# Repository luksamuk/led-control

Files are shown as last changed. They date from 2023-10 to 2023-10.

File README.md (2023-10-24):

# LED Control

Iluminação IoT usando LEDs NeoPixel, controle remoto e mudança automática de iluminação.

A intenção original era criar um sistema simples de iluminação dinâmica para o meu quarto, usando IoT, e também permitir controlar isso remotamente (já que não tenho interruptor próximo à minha cama...), além de mudar automaticamente a iluminação em certos momentos do dia.

## Servidor no Raspberry Pi Pico W

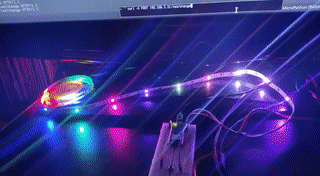
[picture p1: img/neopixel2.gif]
Exemplo do circuito de LEDs em execução


Vamos usar o Raspberry Pi Pico W como um servidor HTTP 1.1 e também como um controlador para os LEDs NeoPixel. Esse dispositivo possui uma antena Wi-Fi, por isso ele é ideal para um servidor HTTP IoT.

### Circuito

Os requisitos mínimos para montar o projeto são:

- Uma protoboard ([uma de 400 pontos](https://www.makerhero.com/produto/protoboard-400-pontos/) é o suficiente);
- Um [Raspberry Pi Pico W](https://www.makerhero.com/produto/raspberry-pi-pico-w/) (deve ser este modelo, para que conectemos ao Wi-Fi -- lembre-se de soldar [pinos](https://www.makerhero.com/produto/barra-de-pinos-1x40-torneada-180-graus/) em ambas as extremidades para conectar à protoboard!);
- 7 [jumpers](https://www.makerhero.com/produto/kit-jumpers-10cm-x120-unidades/) macho-macho (para montar o circuito. Três desses jumpers são saídas para os LEDs, e podem ser substituídos por jumpers macho-fêmea a depender da extremidade usada);
- Uma [Fita de LED RGB WS2812 5050 de 1 metro](https://www.makerhero.com/produto/fita-de-led-rgb-ws2812-5050-1m/);
- Uma [chave táctil push-button](https://www.makerhero.com/produto/chave-tactil-push-button/).

A montagem pode ser feita de acordo com essa [esquemática](./img/breadboard.png).

### Instalação

O projeto encontra-se na pasta `rpi-pico-w`.

1. [Baixe a IDE Thonny](https://thonny.org/).
2. [Conecte seu Raspberry Pi Pico W e instale o MicroPython](https://projects.raspberrypi.org/en/projects/get-started-pico-w/1).
2. Vá ao menu `Ferramentas` > `Gerenciar pacotes`. Instale os pacotes `picozero` e `neopixel`.
3. Abra o arquivo `main.py`. Altere as variáveis `SSID` e `PASSWD` para as suas credenciais do seu Wi-Fi.
4. Você poderá executar a aplicação para testar nesse momento. Para fazer com que o MicroPython fique responsivo novamente, basta parar a aplicação.
5. Após testar, selecione a opção para salvar o script, e salve-o no seu Raspberry Pi Pico W, *exatamente com o nome `main.py`*.

Caso você tenha acesso à sua configuração do roteador, recomendo definir um IP estático para o Raspberry Pi Pico W.

### Comportamento e Rotas

Abaixo temos uma breve descrição dos comportamentos do servidor e das rotas que podem ser usadas.

**Todas as rotas retornam um documento JSON** com o seguinte formato:

```json
{
    "blinking": true,
    "program": 2,
    "dim": 0.1474,
    "color": "ffa648"
}
```

- `blinking`: Se os LEDs estão ligados ou não.
- `program`: Programa sendo executado. Os programas são sempre um dos números `0` (modo Natal), `1` (modo Rastro) e `2` (modo Lâmpada -- padrão).
- `dim`: Nível de intensidade da luz. Deve ser um número entre `0.02` e `1.0`.
- `color`: Cor atual dos LEDs (apenas para o modo Lâmpada). Trata-se de uma string com valores hexadecimais no formato `ffffff`.

Os valores de `program`, `dim` e `color` podem ser alterados e retornados normalmente, mesmo que o LED esteja desativado. Igualmente, o valor de `color` também pode ser alterado e retornado, mesmo que o equipamento não esteja no modo Lâmpada.

Caso você realize uma requisição em uma rota desconhecida, o servidor retornará um erro `404`.

#### Status do servidor

- `GET /led`

Retorna o status da aplicação, sem realizar nenhuma modificação.

#### Ligar/Desligar

- `POST /led/on`
- `POST /led/off`
- `POST /led/toggle`

Liga ou desliga os LEDs. Desligar os LEDs não desligará o servidor. A terceira rota inverte o estado atual de ligado/desligado.

#### Mudar programação

- `POST /led/program/{id}`
- `POST /led/change`

Muda a atual programação dos LEDs. A primeira rota coloca uma programação em específico, e a segunda muda para a próxima programação na ordem. O `id` dever corresponder ao número do programa, como descrito mais acima.

#### Mudar intensidade

- `POST /led/dim/{valor}`

Muda a intensidade da luz dos LEDs, em qualquer modo. O `valor` deve ser um valor entre `0.02` e `1.0`.

#### Mudar cor

- `POST /led/color/{hex}`

Define a cor dos LEDs, apenas para o modo Lâmpada. O `hex` deve ser uma cor em hexadecimal no formato `ffffff`.

## Controle Remoto

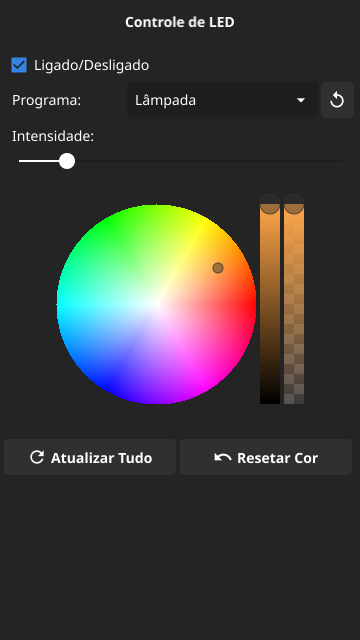
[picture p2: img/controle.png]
Controle remoto para o servidor HTTP


O controle remoto foi projetado para que seja possível controlar o servidor de LEDs remotamente, interagindo via requisições HTTP, especialmente pelo celular Android, mas também pode ser utilizado no desktop ou em outros sistemas. Ele funcionará normalmente caso você esteja conectado à mesma rede do seu Raspberry Pi Pico W.

### Testando a aplicação

Para compilar a aplicação, você precisa ter o compilador de Go 1.21.0 ou superior. Para compilar para o Android, instale Docker e a ferramenta [`fyne-cross`](https://github.com/fyne-io/fyne-cross).

Comece abrindo o arquivo `internal/wsclient/wsclient.go`. Altere a constante `BASEURL` para o IP fixo do seu Raspberry Pi Pico W.

Em seguida, para testar a aplicação, execute:

```bash
go run .
```

### Compilando para Android

Você poderá compilar sua aplicação para Android entrando na pasta `LEDControl` e executando o comando `make`, caso você tenha o GNU Makefile instalado. Caso contrário, use diretamente o `fyne-cross`:

```bash
fyne-cross android \
    -app-id com.luksamuk.ledcontrol \
    -icon Icon.png
```

*NOTA:* Para o Go 1.21.0, em 16/10/2023, a compilação com `fyne-cross` está quebrada. Recomendo instalar o `fyne-cross`, e instalar Go 1.20 [através da ferramenta GVM](https://github.com/moovweb/gvm).

## Serviço Web

Documentação em breve.

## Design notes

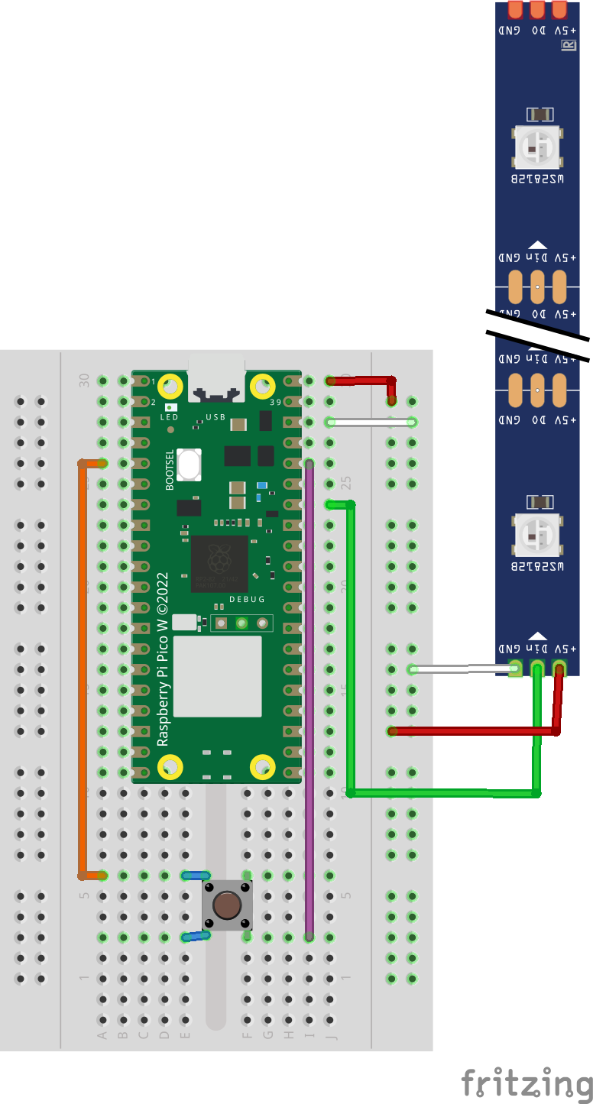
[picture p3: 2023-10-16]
img/breadboard.png

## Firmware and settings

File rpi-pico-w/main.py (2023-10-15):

from machine import Pin
from neopixel import NeoPixel
from time import sleep, ticks_ms
from picozero import pico_led
import network
import socket
import select
import struct
import binascii

# Definitions for pins
pin = Pin(28)
button = Pin(3, Pin.IN, Pin.PULL_DOWN)

# Definitions for NeoPixel LEDs
np = NeoPixel(pin, 30)
programming = 2          # Default to lamp

# Definitions for WiFi
SSID   = 'CHANGEME'
PASSWD = 'CHANGEME'
wlan   = network.WLAN(network.STA_IF)

# Definitions for REST server
rest_socket = None
rest_poller = None

# Global state
blinking = True
pressed_old = False
pressed_current = False
last_blink_ms = 0
dim = 0.05
prog2_color = (255, 255, 255)

# All pixel colors which cycle around
# the strip sequentially
pixels_prog0 = [
    (255, 255, 255),
    (0, 0, 0),
    (64,  30,  10),
    (0,    0,   0),
    (30,  64,  10),
    (0,    0,   0),
    (30,  10,  64),
    (0,    0,   0),
    (128, 10,  30),
    (0,    0,   0),
    (10, 128,  30),
    (0,    0,   0),
    (10,  30, 128),
    (0,    0,   0),
    (255, 30,  30),
    (0,    0,   0),
    (30, 255,  30),
    (0,    0,   0),
    (30,  30, 255),
    (0,    0,   0),
    (255, 0, 0),
    (0,    0,   0),
    (255, 165, 0),
    (0,    0,   0),
    (255, 255, 0),
    (0,    0,   0),
    (0, 128, 0),
    (0,    0,   0),
    (0, 0, 255),
    (0,    0,   0),
    (75, 0, 130),
    (0,    0,   0),
    (238, 130, 238),
    (0,    0,   0)
]


# Routine for pressing the button
def pressed():
    global button
    global pressed_old
    global pressed_current
    pressed_current = button.value()
    state = False
    if not (pressed_current == pressed_old):
        if pressed_current:
            state = True
    pressed_old = pressed_current
    return state

# Shut lights off
def lights_off():
    global np
    for i in range(np.n):
        np[i] = (0, 0, 0)
    np.write()

# Change lights dim
def set_dim(dimstr):
    global dim
    print(f'set dim: {dimstr}')
    try:
        deltadim = float(dimstr)
        if (deltadim > 0) and (deltadim <= 1):
            dim = deltadim
    except:
        pass

# Change lantern program color
def set_color(colorstr):
    global prog2_color
    print(f'set color: {colorstr}')
    try:
        r, g, b = bytes.fromhex(colorstr)
        prog2_color = (r, g, b)
    except:
        pass

# Change current program
def set_program(programstr):
    global programming
    print(f'set program: {programstr}')
    try:
        prog = int(programstr)
        if (prog >= 0) and (prog < 3):
            programming = prog
            lights_off()
    except:
        pass
    
# Routine for toggling state
def toggle():
    global blinking
    blinking = not blinking
    if not blinking:
        lights_off()

# Routine for changing the program
def cycle_program():
    set_program((programming + 1) % 3)
        
# Connect to the given WiFi network
def wlan_connect(ssid, password):
    wlan.active(True)
    print('Scanning for networks...')
    wlan.scan()
    print(f'Connecting to {ssid}...')
    wlan.connect(ssid, password)
    while not wlan.isconnected():
        pico_led.toggle()
        sleep(0.2)
    ip = wlan.ifconfig()[0]
    print(f'Connected. IP address: {ip}')
    pico_led.on()
    return ip

# Create a REST socket. Returns a poller and the socket itself.
def start_rest_socket(ip):
    address = (ip, 80)
    rest_socket = socket.socket()
    rest_socket.bind(address)
    rest_socket.listen(1)
    poller = select.poll()
    poller.register(rest_socket, select.POLLIN)
    print(f'Socket listening to {address[0]}:{address[1]}.')
    return (poller, rest_socket)

# Functions for REST responses
def respond_status(client):
    global blinking
    global dim
    global programming
    global prog2_color
    value = 'true' if blinking else 'false'
    color = binascii.hexlify(struct.pack('BBB', *prog2_color)).decode('utf-8')
    client.send('HTTP/1.1 200 OK\r\n')
    client.send('Content-Type: application/json\r\n')
    client.send('Connection: close\r\n')
    client.send(f'\n\r{{"blinking": {value}, "program": {programming}, "dim": {dim}, "color": "{color}"}}\r\n')

def respond_notfound(client):
    client.send('HTTP/1.1 404 Not Found\r\n')
    client.send('Connection: close\r\n')

# Poll and respond to REST events
def poll_rest_event():
    global rest_poller
    global blinking
    global programming
    res = rest_poller.poll(16)
    if res:
        client = res[0][0].accept()[0]
        request = client.recv(1024).decode('utf-8')
        # Get first line
        request = request.partition('\r\n')[0]
        print(request)
        if request.startswith('POST /led/toggle '):
            toggle()
            respond_status(client)
        elif request.startswith('POST /led/change '):
            cycle_program()
            respond_status(client)
        elif request.startswith('POST /led/on '):
            blinking = True
            respond_status(client)
        elif request.startswith('POST /led/off '):
            blinking = False
            lights_off()
            respond_status(client)
        elif request.startswith('POST /led/dim/'):
            trimright = str(request)[:-9]
            set_dim(trimright[14:])
            respond_status(client)
        elif request.startswith('POST /led/color/'):
            trimright = str(request)[:-9]
            set_color(trimright[16:])
            respond_status(client)
        elif request.startswith('POST /led/program/'):
            trimright = str(request)[:-9]
            set_program(trimright[18:])
            respond_status(client)
        elif request.startswith('GET /led '):
            respond_status(client)
        else:
            respond_notfound(client)
        client.close()

# INDEX
i = 0

# Constant white light programming
def programming2():
    global np
    global blinking
    global dim
    if blinking:
        px = ((int)(dim * prog2_color[0]), (int)(dim * prog2_color[1]), (int)(dim * prog2_color[2]))
        for i in range(np.n):
            np[i] = px
            np.write()

# Blinking LED programmings
def programming0():
    global i
    global blinking
    global np
    global last_blink_ms
    global pixels_prog0
    global dim
    
    num_pixels = len(pixels_prog0)
    current_time_ms = ticks_ms()
    if (current_time_ms - last_blink_ms >= 100): # Blink every 100ms
        if blinking:
            i = (i + 1) % num_pixels
            for j in range(np.n):
                color = pixels_prog0[(i + j) % num_pixels]
                np[j] = ((int)(dim * color[0]), (int)(dim * color[1]), (int)(dim * color[2]))
            np.write()
        last_blink_ms = current_time_ms


# Back-and-forth trail of lights
going_back = False
current_color = 0
def programming1():
    global i
    global blinking
    global np
    global last_blink_ms
    global going_back
    global pixels_prog0
    global current_color
    global dim
    current_time_ms = ticks_ms()
    if (current_time_ms - last_blink_ms >= 20): # Blink every 16ms
        if blinking:
            if ((not going_back) and (i == np.n - 1)) or (going_back and (i == 0)):
                going_back = not going_back
                current_color = (current_color + 2) % len(pixels_prog0)
            if not going_back:
                i = (i + 1) % np.n
                j = (i - 1) % np.n
            elif going_back:
                i = (i - 1) % np.n
                j = (i + 1) % np.n
            #np[i] = (255, 255, 255)
            color = pixels_prog0[current_color]
            np[i] = ((int)(dim * color[0]), (int)(dim * color[1]), (int)(dim * color[2]))
            np[j] = (0, 0, 0)
            np.write()
        last_blink_ms = current_time_ms

# Blinking lights loop, should be spawned asynchronously
def blink_lights_loop():
    global programming
    while True:
        sleep(0.001) # 1ms
        if programming == 0:
            programming0()
        elif programming == 1:
            programming1()
        elif programming == 2:
            programming2()
        else:
            lights_off()
        # Toggle LED if button was pressed
        if pressed():
            toggle()
        # Execute REST events
        poll_rest_event()

if __name__ == "__main__":
    try:
        # Turn lights off if any
        lights_off()
    
        # Light on onboard LED
        pico_led.on()
    
        # Connect to WiFi
        ip = wlan_connect(SSID, PASSWD)
    
        # Start REST server
        rest_poller, rest_socket = start_rest_socket(ip)
    
        # Run on non-interpreter thread
        print('Starting main loop')
        blink_lights_loop()
    except:
        # On exceptions, restart RPi Pico W.
        # This avoids errors such as Address in Use for sockets.
        machine.reset()

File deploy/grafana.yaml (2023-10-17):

---
apiVersion: v1
kind: ConfigMap
metadata:
  name: grafana-datasources
  namespace: iot
data:
  iot-datasources.yaml: |
    apiVersion: 1
    datasources:
      - name: Prometheus
        type: prometheus
        access: proxy
        url: http://prometheus:9090
---
apiVersion: v1
kind: ConfigMap
metadata:
  name: grafana-webconfig
  namespace: iot
data:
  grafana.ini: |
    [server]
    domain = localhost
    root_url = %(protocol)s://%(domain)s:%(http_port)s/dashboard/
    serve_from_sub_path = true
---
apiVersion: traefik.containo.us/v1alpha1
kind: Middleware
metadata:
  name: grafana-ingress-middleware
  namespace: iot
spec:
  replacePathRegex:
    regex: ^/dashboard/(.*)
    replacement: /$1
---
apiVersion: networking.k8s.io/v1
kind: Ingress
metadata:
  name: grafana-ingress
  namespace: iot
  annotations:
    kubernetes.io/ingress.class: traefik
    traefik.ingress.kubernetes.io/router.middlewares: iot-grafana-ingress-middleware@kubernetescrd
spec:
  rules:
    - http:
        paths:
          - path: /dashboard
            pathType: Prefix
            backend:
              service:
                name: grafana
                port:
                  number: 3000
---
apiVersion: v1
kind: Service
metadata:
  name: grafana
  namespace: iot
spec:
  type: LoadBalancer
  ports:
    - port: 3000
      protocol: TCP
      targetPort: http-grafana
      nodePort: 31998
  selector:
    app: grafana
  sessionAffinity: None
---
apiVersion: apps/v1
kind: Deployment
metadata:
  labels:
    app: grafana
  name: grafana
  namespace: iot
spec:
  selector:
    matchLabels:
      app: grafana
  template:
    metadata:
      labels:
        app: grafana
    spec:
      securityContext:
        fsGroup: 472
        supplementalGroups:
          - 0
      containers:
        - name: grafana-container
          image: grafana/grafana:9.2.4
          imagePullPolicy: IfNotPresent
          ports:
            - containerPort: 3000
              name: http-grafana
              protocol: TCP
          readinessProbe:
            failureThreshold: 3
            httpGet:
              path: /robots.txt
              port: 3000
              scheme: HTTP
            initialDelaySeconds: 10
            periodSeconds: 30
            successThreshold: 1
            timeoutSeconds: 2
          livenessProbe:
            failureThreshold: 3
            initialDelaySeconds: 30
            periodSeconds: 10
            successThreshold: 1
            tcpSocket:
              port: 3000
            timeoutSeconds: 1
          resources:
            requests:
              cpu: 250m
              memory: 750Mi
          volumeMounts:
            - mountPath: /var/lib/grafana
              name: grafana-pv
            - mountPath: /etc/grafana
              name: grafana-webconfig
            - mountPath: /etc/grafana/provisioning/datasources
              name: grafana-datasources
      volumes:
        - name: grafana-pv
          persistentVolumeClaim:
            claimName: grafana-pvc
        - name: grafana-webconfig
          configMap:
            name: grafana-webconfig
        - name: grafana-datasources
          configMap:
            name: grafana-datasources
---
apiVersion: v1
kind: PersistentVolumeClaim
metadata:
  name: grafana-pvc
  namespace: iot
spec:
  accessModes:
    - ReadWriteOnce
  resources:
    requests:
      storage: 1Gi

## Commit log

2023-10-15 Add RPi Pico W script with extra routes
2023-10-15 Fix bugs on new routes and payloads for Pico script
    [main.py]
2023-10-15 Ignore pitch black and fix a bug when raising errors on color change
2023-10-15 Use a proper combo box to change current program
2023-10-16 Add proper documentation and license
    [schematics.fzz]
2023-10-18 Make program report inactivity status when LED is off
